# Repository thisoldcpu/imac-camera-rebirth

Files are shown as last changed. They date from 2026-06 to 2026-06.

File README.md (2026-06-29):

# iMac Camera Rebirth

**Open hardware project for repurposing 2009–2013 iMac camera modules into modern USB-C webcams.**






Every year, thousands of otherwise functional iMacs are scrapped due to broken displays, failed logic boards, or obsolete hardware. Their camera modules are often still fully functional, compact, factory-calibrated USB devices destined for e-waste.

**imac-camera-rebirth** documents everything needed to give these cameras a second life.

Whether you want to build your own, integrate one into a robotics project, or simply purchase a ready-to-use webcam, this repository contains the documentation, CAD files, wiring information, and compatibility notes to make it possible.



wires

## Features

* Reuses genuine OEM iMac camera modules
* Native USB 2.0 operation
* USB-C compatible
* No microcontroller required
* Open CAD designs
* Open documentation and pinouts
* Compact desktop and embedded enclosure designs

## Planned Hardware

* **Studio** — Cylindrical desktop webcam inspired by classic desktop camera designs.
* **Wedge** — Ultra-compact enclosure for robotics, photogrammetry, machine vision, kiosks, and custom installations.

## Compatibility

| iMac |  Camera  | USB |  Tested | Notes |
| ---- | :---: | :-: | :-----: | --- |
| 2009 | Module A |  ✔  | ✔ | Native UVC |
| 2010 | Module B |  ✔  | ✔ | Dual microphone |
| 2011 | Module C |  ✔  | ✔ | Different mounting holes |
| 2012 | Module D |  ✔  | Pending | Alternate bracket required |
| 2013 | Module E |  ✔  | Pending | Alternate bracket required |

## Repository Contents

```
/cad            CAD models and printable enclosures
/docs           Pinouts, teardown notes, compatibility
/photos         Reference images and assembly photos
/reference      Apple part numbers and donor identification
```

## Project Goals

* Reduce electronic waste through hardware reuse.
* Document every known compatible camera module.
* Create high-quality, printable enclosures.
* Keep the project entirely firmware-free whenever possible.
* Make professional-quality USB webcams from discarded hardware.

## Disclaimer

Apple and iMac are trademarks of Apple Inc. This is an independent open hardware project and is not affiliated with, sponsored by, or endorsed by Apple. All camera modules referenced by this project are reclaimed from donor hardware.

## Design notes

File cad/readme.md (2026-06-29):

# CAD

This folder contains the CAD source files and printable exports for the iMac Camera Rebirth enclosure designs.

The project uses OpenSCAD for editable source geometry and exports STL / 3MF files for printing.

## Folder Layout

| Folder | Purpose |
| --- | --- |
| `/cad/scad` | Editable OpenSCAD source files. This is the CAD source of truth. |
| `/cad/export` | Generated printable files exported from the OpenSCAD source. |

## Source Files

The OpenSCAD files live in:

```text
/cad/scad
```

These files define the enclosure geometry, shared parameters, module-specific dimensions, and printable part variants.

Use these files when you want to:

* modify the design
* create a new enclosure variant
* adjust tolerances
* add a new camera module carrier
* regenerate STL or 3MF exports

## Exported Print Files

Printable exports live in:

```text
/cad/export
```

The export folder contains generated mesh and print-project files intended for slicers and printers.

Current export formats include:

| Format | Folder | Notes |
| --- | --- | --- |
| STL | `/cad/export/stl` | Universal mesh exports for broad slicer compatibility. |
| 3MF | `/cad/export/3mf` | Modern print exports and Bambu Studio project files. |

For most users, the recommended print files are the prepared `.3mf` projects because they preserve more print intent than STL files.

## Enclosure Families

Current enclosure work includes:

| Enclosure | Description |
| --- | --- |
| Obelisk | Rectangular monolith-style enclosure with interchangeable bottom / mount variants. |
| Cylinder  | Cylindrical desktop enclosure using original internal geometry and modern USB-C layout. |

Both enclosure styles may support either direct USB camera modules or builds that require an internal MCU / bridge board.

The enclosure shape does not define the electronics path.

## Design Model

The CAD is organized around four separate concerns:

```text
Enclosure style  = visible outer shell
Camera module    = reclaimed iMac camera variant
Electronics path = direct USB or bridge / MCU
Mounting style   = wedge, plate, monitor, M6+, VESA, etc.
```

The goal is to keep the visible enclosure designs reusable while allowing module-specific carriers, wiring approaches, and mounting bases to evolve independently.

## Source of Truth

The editable source of truth is always:

```text
/cad/scad
```

The files in `/cad/export` are generated build artifacts.

When the OpenSCAD source changes, regenerate the matching STL / 3MF exports so the repository stays in sync.

## Notes

STL files contain only mesh geometry.

3MF files may preserve additional print setup information, depending on how they were exported. Bambu Studio `.3mf` files may include plate layout, filament assignments, and support-material configuration.

For the current Obelisk print, the Bambu Studio project uses PLA support material for support interfaces. This setting matters and may not survive conversion to other formats.

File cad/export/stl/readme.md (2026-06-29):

# Obelisk STL Exports

This folder contains exported `.stl` mesh files for the Obelisk enclosure.

These files are generated from the OpenSCAD source files in:

```text
/cad/scad
```

STL files are provided for broad slicer and printer compatibility. They are useful for users who want to slice the parts manually, inspect the geometry, or use printers that do not handle `.3mf` files well.

For the known-good Bambu Studio print setup, use the `.3mf` exports instead:

```text
/cad/export/3mf
```

## Files

| File | Source | Description |
| --- | --- | --- |
| `obelisk_top.stl` | OpenSCAD | v0 top shell mesh export. |
| `obelisk_bottom.stl` | OpenSCAD | v0 bottom shell / mount plate mesh export. |
| `obelisk_top_v1.stl` | OpenSCAD | v1 top shell mesh export. |
| `obelisk_bottom_v1.stl` | OpenSCAD | v1 bottom shell / mount plate mesh export. |

## Recommended STL Files

Use the latest matching top and bottom pair:

obelisk_bottom_v1
obelisk_top_v1

```text
obelisk_top_v1.stl
obelisk_bottom_v1.stl
```

These two parts form the current Obelisk v1 enclosure.

The top shell contains the primary enclosure walls, USB-C opening, camera module clearance, and internal support posts.

The bottom part is not just a lid. It is also the mount interface. The recessed area in the bottom part is intentional and defines how the enclosure attaches to future bases or mounting plates.

## STL Limitations

STL files contain only mesh geometry.

They do not preserve:

```text
filament assignments
support material settings
support interface material
print orientation intent
slicer modifiers
printer profile settings
plate layout
```

This matters for Obelisk because the prepared Bambu Studio `.3mf` project uses PLA support material for support interfaces.

When printing from STL, manually confirm your slicer settings before printing.

## Support Material Warning

The Obelisk enclosure includes internal features and supported surfaces that benefit from clean support separation.

The prepared `.3mf` project uses:

```text
Model material: selected body material
Support interface: PLA support material
```

STL exports do not preserve this setup.

When slicing the STL files manually, review:

```text
support enablement
support interface material
top Z distance
bottom Z distance
support/object XY distance
overhang handling
internal support removal access
```

For the intended Bambu Studio setup, use:

```text
/cad/export/3mf/obelisk_v1.3mf
```

## Bottom / Mount Plate Design

The Obelisk bottom is intentionally exported as a singular model.

The recessed area is the mounting interface. This allows the visible top shell to remain shared while different bottom variants provide different installation options.

Planned bottom / mount variants include:

```text
M6+ mount
Wedge base
Bottom plates
Monitor clip base
VESA / arm mount
```

Future mount-specific STL exports should use descriptive filenames:

```text
obelisk_bottom_m6_v1.stl
obelisk_bottom_wedge_v1.stl
obelisk_bottom_plate_v1.stl
obelisk_bottom_monitor_clip_v1.stl
obelisk_bottom_vesa_v1.stl
```

## Version Notes

`v0` files represent the first printable OpenSCAD mesh exports.

`v1` files represent the first revised Obelisk shell geometry intended for practical test printing.

Future versions should use the same naming pattern:

```text
obelisk_top_v2.stl
obelisk_bottom_v2.stl
obelisk_bottom_m6_v2.stl
obelisk_bottom_wedge_v2.stl
```

## Source of Truth

The STL files are generated build artifacts.

The editable source of truth remains the OpenSCAD source in:

```text
/cad/scad
```

If the OpenSCAD geometry changes, regenerate the matching STL exports so the printable mesh files remain in sync with the CAD source.

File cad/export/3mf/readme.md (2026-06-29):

# Obelisk 3MF Exports

This folder contains exported `.3mf` files for the Obelisk enclosure.

These files are generated from the OpenSCAD source files in:

```text
/cad/openscad
```

Some files are direct OpenSCAD exports of individual parts. Others are Bambu Studio project exports prepared as complete print layouts.

## Files

| File | Source | Description |
| --- | --- | --- |
| `obelisk.3mf` | Bambu Studio | Complete Obelisk print layout exported as a single print job. |
| `obelisk_v1.3mf` | Bambu Studio | Complete Obelisk v1 print layout with PLA support material configured. |
| `obelisk_v1_preview.png` | Bambu Studio | Screenshot preview of the v1 layout with PLA support material. |
| `obelisk_top.3mf` | OpenSCAD | v0 top shell export. |
| `obelisk_bottom.3mf` | OpenSCAD | v0 bottom shell / mount plate export. |
| `obelisk_top_v1.3mf` | OpenSCAD | v1 top shell export. |
| `obelisk_bottom_v1.3mf`  | OpenSCAD | v1 bottom shell / mount plate export. |

## Recommended Print

Use the latest complete Bambu Studio project unless you specifically need individual parts:

```text
obelisk_v1.3mf
```

This file contains the v1 top and bottom components arranged as a single print job.

obelisk_v1_preview

The v1 project is configured to use **PLA support material** for support interfaces. This matters. The support-material assignments are part of the intended print setup and may be lost if the file is imported into another slicer or reconfigured manually.

## Support Material

The Obelisk print uses support material where needed for clean internal features and removable support contact surfaces.

Current Bambu Studio setup:

```text
Model material: PLA / PETG / selected body material
Support interface: PLA support material
```

Before printing, confirm that the slicer has preserved the intended support-material assignments.

## Bottom / Mount Plate Design

The Obelisk bottom is intentionally a single printable model.

The recessed area in the bottom part is the mount interface. Future bottom variants will use this same design pattern for alternate mounting styles.

Planned bottom / mount variants include:

```text
M6+ mount
Wedge base
Bottom plates
Monitor clip base
VESA / arm mount
```

The top shell is shared across variants. The bottom part defines the mounting behavior.

This keeps the visible enclosure consistent while allowing different installation styles.

## Individual Part Exports

The individual top and bottom `.3mf` files are provided for users who want to:

* slice the parts manually
* modify orientation
* use a different printer profile
* print only one half of the enclosure
* compare v0 and v1 geometry
* develop alternate bottom / mount variants

## Version Notes

`v0` files represent the first printable OpenSCAD export.

`v1` files include the first revised Obelisk shell geometry intended for practical test printing.

Future versions should use the same naming pattern:

```text
obelisk_top_v2.3mf
obelisk_bottom_v2.3mf
obelisk_v2.3mf
obelisk_v2_preview.png
```

Mount-specific bottom variants should use descriptive names:

```text
obelisk_bottom_m6_v1.3mf
obelisk_bottom_wedge_v1.3mf
obelisk_bottom_plate_v1.3mf
obelisk_bottom_vesa_v1.3mf
```

## Notes

The `.3mf` files are exported build artifacts. The editable source of truth remains the OpenSCAD files in `/cad/openscad`.

If you modify the CAD, regenerate the matching export files so the source and printable outputs stay in sync.

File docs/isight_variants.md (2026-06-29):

# iSight Camera Module Variants

This document tracks known internal iMac iSight camera modules that can be reclaimed and reused as USB webcams.

Each module may use different connectors, harness colors, mounting hardware, or mechanical dimensions. Do not assume wire colors are universal across variants. Always confirm continuity and pinout before applying power.

## Known Variants

| Module PCB | Donor System | Harness | USB VID/PID | Status |
| --- | --- | --- | --- | --- |
| 820-2572-A | 27" iMac, Late 2009 | 593-1027 A | `VID_05AC&PID_8502` | Video confirmed |

---

# Apple 820-2572-A



820-2572-A_image_quality

Image captured using OBS video capture and the Apple Built-in iSight camera via USB-C

## Summary

| Item | Value |
| --- | --- |
| Donor system | 27" Apple iMac, Late 2009 |
| PCB marking | `820-2572-A` |
| Aluminum shim | `806-02600` |
| Plastic frame | `8T98PEEC2 77K3L00` |
| Harness | `593-1027 A` |
| Harness colors observed | Black, brown, white, purple, grey |
| USB VID/PID | `VID_05AC&PID_8502` |
| Windows raw name | `Built-in iSight` |
| Windows installed name  | `Apple Built-in iSight` |
| Video capture | Confirmed |

This module operates as a native USB 2.0 camera once wired to USB VBUS, GND, D+, and D-. No microcontroller, firmware bridge, or conversion logic is required.

## Status

| Test | Result |
| --- | --- |
| USB enumeration | Confirmed |
| Windows device detection | Confirmed |
| Driver association | Confirmed |
| Video capture | Confirmed |

## Windows Notes

On Windows, this module initially appears as:

```text
Built-in iSight
```

Observed hardware ID:

```text
VID_05AC&PID_8502
```

After driver association, Device Manager identifies the camera as:

```text
Apple Built-in iSight
```

Testing used `AppleNullDriver64.exe` version `2.1.1.1`, extracted to a folder and installed manually through Device Manager.

We do not redistribute Apple driver packages in this repository.
Users are responsible for obtaining any Apple or Boot Camp driver files from their own legally obtained sources.

## Wiring

Observed harness: `593-1027 A`

Connector orientation note: Pin 1 is marked by the arrow near the connector, closest to the PCB edge.

| Pin | Wire color | Function | USB connection |
| --: | --- | --- | --- |
| 1 | Black | Chassis / shield ground | USB GND / connector shell |
| 2 | Brown | +5V | USB VBUS |
| 3 | Purple | USB D- | USB D- |
| 4 | White | USB D+ | USB D+ |
| 5 | Grey | USB ground | USB GND |

## Ground / Chassis Notes

On this module, chassis/shield ground and USB ground are bonded.

Both Pin 1 and Pin 5 should tone to the heatsink / thermal pad area.

For a simple USB-C breakout wiring harness, both Pin 1 and Pin 5 may be connected to USB ground. Pin 1 may also be bonded to the USB-C connector shell if the breakout exposes shell ground.

## USB-C Breakout Mapping

| iSight Pin | Signal | USB-C breakout |
| ---: | --- | --- |
| 1 | Chassis / shield ground | GND / shield |
| 2 | +5V | VBUS |
| 3 | D- | D- |
| 4 | D+ | D+ |
| 5 | USB ground | GND |

## Mechanical Notes

The aluminum shim appears to function as a thermal spreader rather than a required structural mount.

The PCB includes a thermal pad area that originally mates thermally into the iMac chassis assembly. Enclosure designs should preserve a thermal path or provide a small heatsink / clearance channel above this region.

## Caution

Wire colors may differ between harness revisions, donor machines, or module variants.

Before applying power:

1. Confirm ground continuity.
2. Confirm chassis/shield behavior.
3. Verify VBUS is not shorted to ground.
4. Confirm D+ and D- orientation.
5. Test USB enumeration before final enclosure assembly.

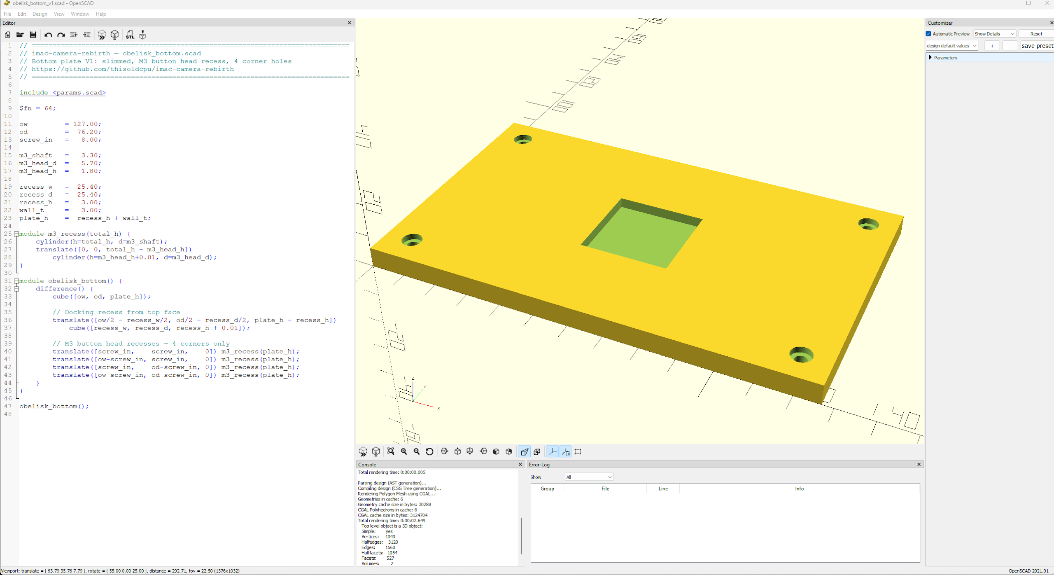
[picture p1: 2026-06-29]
cad/export/stl/obelisk_bottom_v1.png

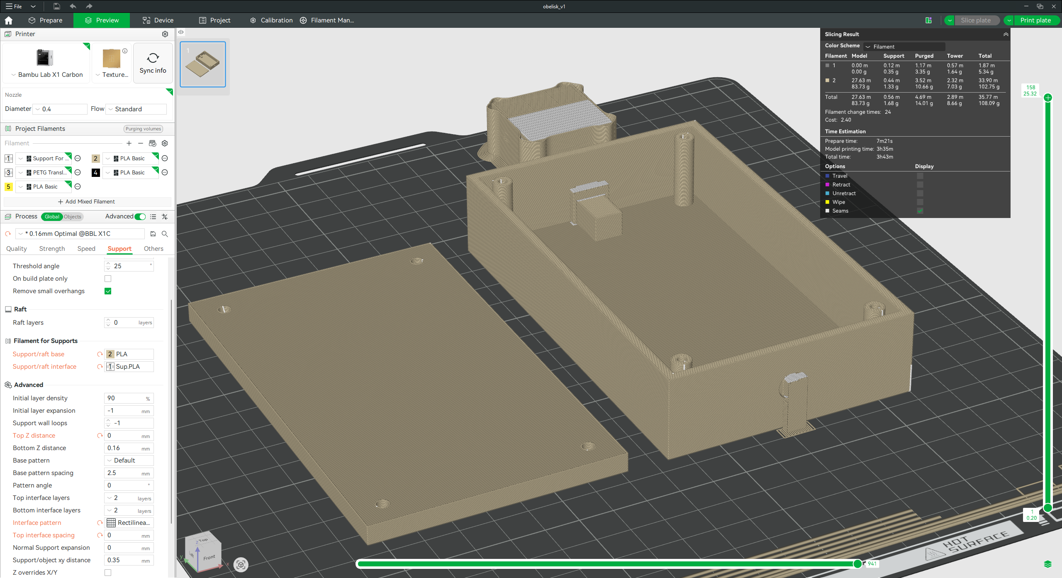
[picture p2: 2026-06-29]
cad/export/3mf/obelisk_v1_preview.png

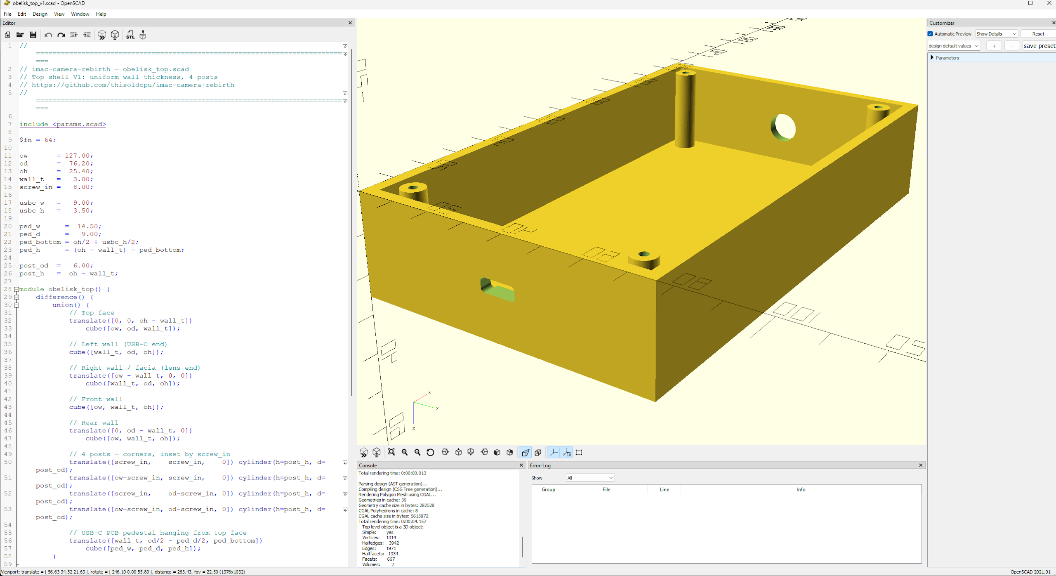
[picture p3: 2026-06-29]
cad/export/stl/obelisk_top_v1.png

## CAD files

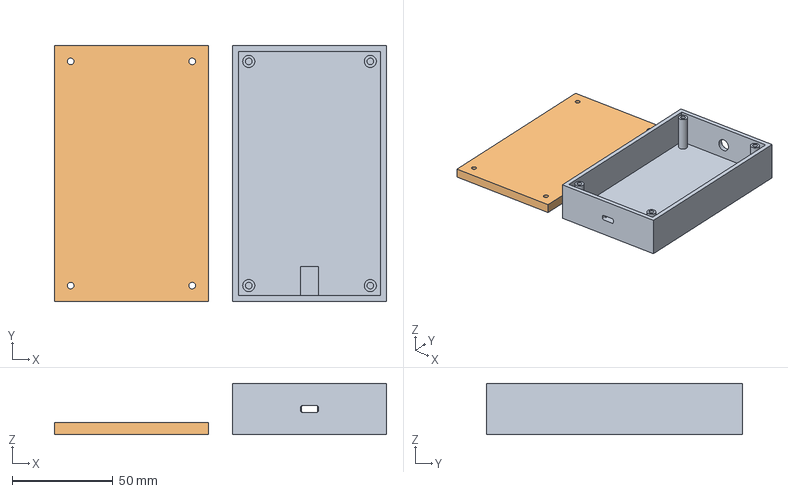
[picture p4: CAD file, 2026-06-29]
cad/export/3mf/obelisk_v1.3mf
164.4 x 127.0 x 25.4 mm

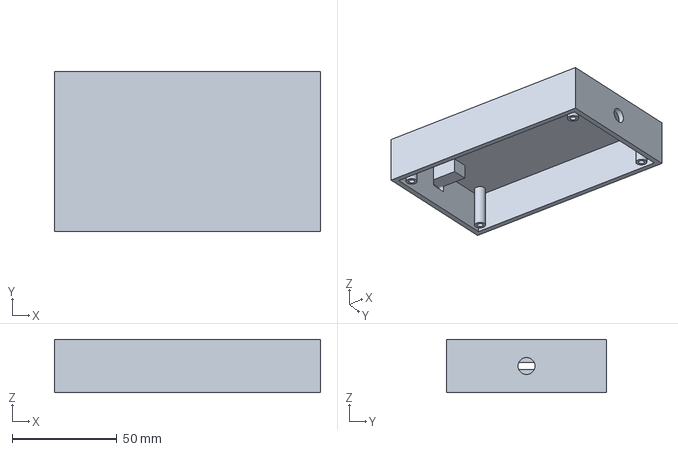
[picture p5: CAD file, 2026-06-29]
cad/export/3mf/obelisk_top_v1.3mf
127.0 x 76.2 x 25.4 mm

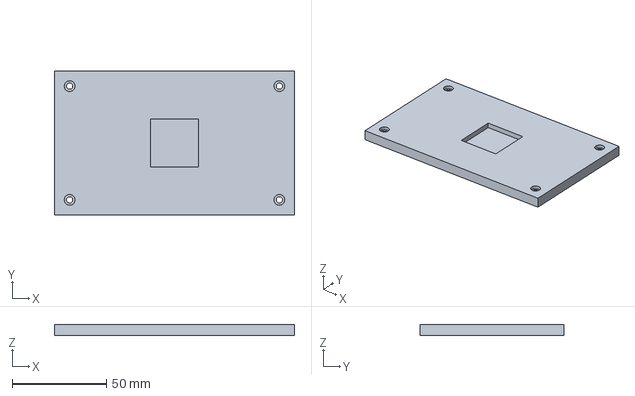
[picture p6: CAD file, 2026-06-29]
cad/export/3mf/obelisk_bottom_v1.3mf
127.0 x 76.2 x 6.00 mm

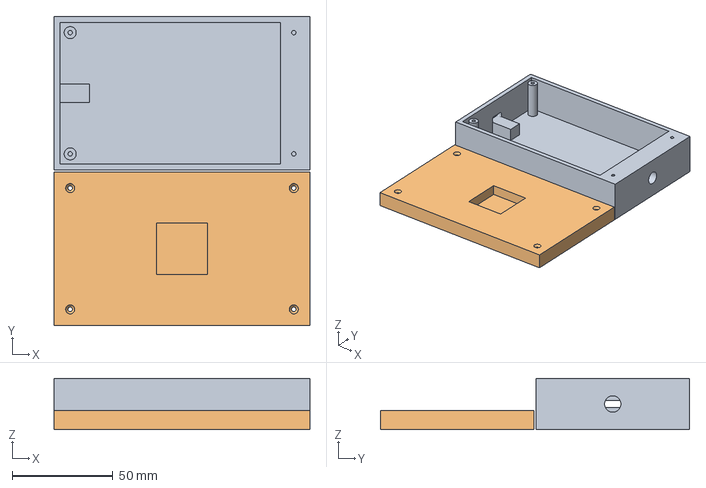
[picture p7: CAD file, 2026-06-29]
cad/export/3mf/obelisk_bottom.3mf
127.0 x 153.4 x 25.4 mm

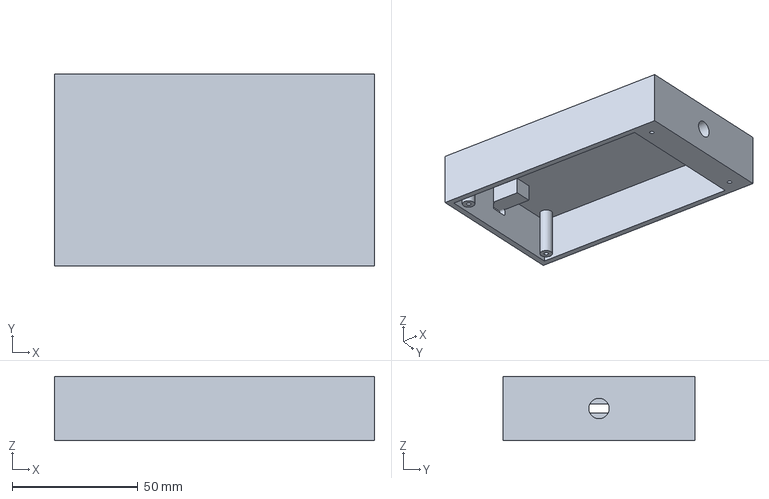
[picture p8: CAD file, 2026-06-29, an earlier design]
cad/export/3mf/obelisk_top.3mf
127.0 x 76.2 x 25.4 mm

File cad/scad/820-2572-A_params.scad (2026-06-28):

// =============================================================================
// imac-camera-rebirth — 820-2572-A params.scad
// Shared parameters for all enclosure variants
// https://github.com/thisoldcpu/imac-camera-rebirth
// =============================================================================
// Module: Apple 820-2572-A (2009 iMac 27")
// =============================================================================

// -----------------------------------------------------------------------------
// PCB
// -----------------------------------------------------------------------------
pcb_l        = 50.00;   // length (X)
pcb_w        =  7.92;   // width (Y)
pcb_d        = 10.00;   // depth lens face to rear connector (Z)

// -----------------------------------------------------------------------------
// Lens barrel
// -----------------------------------------------------------------------------
lens_dia     =  7.50;   // barrel outer diameter
lens_x       = 25.00;   // center offset from PCB left edge (dead center)
lens_y       =  3.96;   // center offset from PCB bottom edge (PCB centerline)

// -----------------------------------------------------------------------------
// USB-C port cutout (rear, dead center)
// -----------------------------------------------------------------------------
usbc_w       =  9.00;   // USB-C receptacle width
usbc_h       =  3.26;   // USB-C receptacle height
usbc_x       = pcb_l / 2; // dead center on PCB length axis

// -----------------------------------------------------------------------------
// Wall and clearance
// -----------------------------------------------------------------------------
wall         =  2.00;   // minimum shell wall thickness
clearance    =  0.20;   // PCB pocket fit clearance (per side)
lens_clear   =  0.30;   // lens aperture clearance (radial)

// -----------------------------------------------------------------------------
// Derived — PCB pocket (do not edit)
// -----------------------------------------------------------------------------
pocket_l     = pcb_l + (clearance * 2);
pocket_w     = pcb_w + (clearance * 2);
pocket_d     = pcb_d + clearance;

// -----------------------------------------------------------------------------
// Obelisk body (top shell)
// -----------------------------------------------------------------------------
body_l       = pocket_l + (wall * 2);
body_w       = pocket_w + (wall * 2);
body_d       = pocket_d + wall;

// -----------------------------------------------------------------------------
// Top/bottom shell split
// -----------------------------------------------------------------------------
split_z      = body_d / 2;  // Z height of shell split plane

// -----------------------------------------------------------------------------
// Heatsink channel
// -----------------------------------------------------------------------------
hs_channel_w =  6.00;   // width of slim channel over HS pad
hs_channel_d =  1.00;   // depth of channel recess into top shell

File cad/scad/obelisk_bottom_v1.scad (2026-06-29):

// =============================================================================
// imac-camera-rebirth — obelisk_bottom.scad
// Bottom plate V1: slimmed, M3 button head recess, 4 corner holes
// https://github.com/thisoldcpu/imac-camera-rebirth
// =============================================================================

include <params.scad>

$fn = 64;

ow         = 127.00;
od         =  76.20;
screw_in   =   8.00;

m3_shaft   =   3.30;
m3_head_d  =   5.70;
m3_head_h  =   1.80;

recess_w   =  25.40;
recess_d   =  25.40;
recess_h   =   3.00;
wall_t     =   3.00;
plate_h    =  recess_h + wall_t;

module m3_recess(total_h) {
    cylinder(h=total_h, d=m3_shaft);
    translate([0, 0, total_h - m3_head_h])
        cylinder(h=m3_head_h+0.01, d=m3_head_d);
}

module obelisk_bottom() {
    difference() {
        cube([ow, od, plate_h]);

        // Docking recess from top face
        translate([ow/2 - recess_w/2, od/2 - recess_d/2, plate_h - recess_h])
            cube([recess_w, recess_d, recess_h + 0.01]);

        // M3 button head recesses — 4 corners only
        translate([screw_in,    screw_in,    0]) m3_recess(plate_h);
        translate([ow-screw_in, screw_in,    0]) m3_recess(plate_h);
        translate([screw_in,    od-screw_in, 0]) m3_recess(plate_h);
        translate([ow-screw_in, od-screw_in, 0]) m3_recess(plate_h);
    }
}

obelisk_bottom();

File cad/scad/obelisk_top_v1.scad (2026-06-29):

// =============================================================================
// imac-camera-rebirth — obelisk_top.scad
// Top shell V1: uniform wall thickness, 4 posts
// https://github.com/thisoldcpu/imac-camera-rebirth
// =============================================================================

include <params.scad>

$fn = 64;

ow       = 127.00;
od       =  76.20;
oh       =  25.40;
wall_t   =   3.00;
screw_in =   8.00;

usbc_w   =   9.00;
usbc_h   =   3.50;

ped_w      =  14.50;
ped_d      =   9.00;
ped_bottom = oh/2 + usbc_h/2;
ped_h      = (oh - wall_t) - ped_bottom;

post_od  =   6.00;
post_h   =  oh - wall_t;

module obelisk_top() {
    difference() {
        union() {
            // Top face
            translate([0, 0, oh - wall_t])
                cube([ow, od, wall_t]);

            // Left wall (USB-C end)
            cube([wall_t, od, oh]);

            // Right wall / facia (lens end)
            translate([ow - wall_t, 0, 0])
                cube([wall_t, od, oh]);

            // Front wall
            cube([ow, wall_t, oh]);

            // Rear wall
            translate([0, od - wall_t, 0])
                cube([ow, wall_t, oh]);

            // 4 posts — corners, inset by screw_in
            translate([screw_in,    screw_in,    0]) cylinder(h=post_h, d=post_od);
            translate([ow-screw_in, screw_in,    0]) cylinder(h=post_h, d=post_od);
            translate([screw_in,    od-screw_in, 0]) cylinder(h=post_h, d=post_od);
            translate([ow-screw_in, od-screw_in, 0]) cylinder(h=post_h, d=post_od);

            // USB-C PCB pedestal hanging from top face
            translate([wall_t, od/2 - ped_d/2, ped_bottom])
                cube([ped_w, ped_d, ped_h]);
        }

        // Lens hole through facia
        translate([ow - wall_t - 1, od/2, oh/2])
            rotate([0, 90, 0])
                cylinder(h=wall_t+2, d=lens_dia + lens_clear*2);

        // USB-C rounded rect cutout through left wall
        translate([0, od/2, oh/2])
            rotate([0, 90, 0])
                translate([0, 0, -1])
                    hull() {
                        translate([ usbc_h/2 - 1,  usbc_w/2 - 1, 0]) cylinder(h=wall_t+2, r=1);
                        translate([-usbc_h/2 + 1,  usbc_w/2 - 1, 0]) cylinder(h=wall_t+2, r=1);
                        translate([ usbc_h/2 - 1, -usbc_w/2 + 1, 0]) cylinder(h=wall_t+2, r=1);
                        translate([-usbc_h/2 + 1, -usbc_w/2 + 1, 0]) cylinder(h=wall_t+2, r=1);
                    }

        // M2 through-holes in 4 posts
        translate([screw_in,    screw_in,    -1]) cylinder(h=post_h+2, d=2.2);
        translate([ow-screw_in, screw_in,    -1]) cylinder(h=post_h+2, d=2.2);
        translate([screw_in,    od-screw_in, -1]) cylinder(h=post_h+2, d=2.2);
        translate([ow-screw_in, od-screw_in, -1]) cylinder(h=post_h+2, d=2.2);
    }
}

obelisk_top();

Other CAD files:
cad/export/3mf/obelisk.3mf
cad/scad/params.scad
cad/export/stl/obelisk_bottom.stl
cad/export/stl/obelisk_bottom_v1.stl
cad/export/stl/obelisk_top.stl
cad/export/stl/obelisk_top_v1.stl
cad/scad/obelisk_bottom_v0.scad
cad/scad/obelisk_top_v0.scad

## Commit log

2026-06-27 Add project badges to README
    Added badges for Open Hardware, USB 2.0, USB-C Compatibility, and 3D Printable.
2026-06-28 Add wiring notes for iSight module variant
2026-06-28 Update isight_variants.txt with detection notes
    Added notes about iSight detection and driver installation.
2026-06-28 Add documentation for iSight camera module variants
    This document provides detailed information on the iSight camera module variants, including wiring, status, and mechanical notes.
2026-06-28 Rename params file for clarity
    [820-2572-A_params.scad]
2026-06-29 Add readme for Obelisk 3MF exports
    This readme provides details on the exported 3MF files for the Obelisk enclosure, including file descriptions, recommended print settings, and version notes.
2026-06-29 Add README for Obelisk STL exports
    This file contains detailed information about the Obelisk STL exports, including file descriptions, limitations, and recommendations for use.
2026-06-29 Add readme for Obelisk STL exports
    This readme provides detailed information about the exported STL files for the Obelisk enclosure, including their sources, limitations, and recommendations for use.
2026-06-29 Add README for CAD project and folder structure
